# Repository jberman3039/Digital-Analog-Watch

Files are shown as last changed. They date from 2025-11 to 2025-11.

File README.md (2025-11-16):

# Digital-Analog-Watch
The "Digital Analog Watch" is an ATTiny85-based project that displays hours and minutes using and outer and inner rings of LEDs respectively. The project includes a custom drivers to set and get the time for an D3231 RTC via I2C communication and update the LEDs on the PCB with 74HC595 shift registers. To initially set the time on the RTC, uncomment "#define SET_TIME" in main.c and set the values for HOUR, MINUTE, and SECOND. After initially flashing and running the code, this line must be recommented out and the code reflashed. The RTC will continue to keep accurate time as long as VBAT is connected to a power source such as a CR2032 coin cell battery. To flash the code to the ATTiny85, navigate to the src folder and run the command "make flash". This project was inspired by https://github.com/brunob45/watch/tree/master.

# PCB
The PCB was designed in KiCad 9.0.
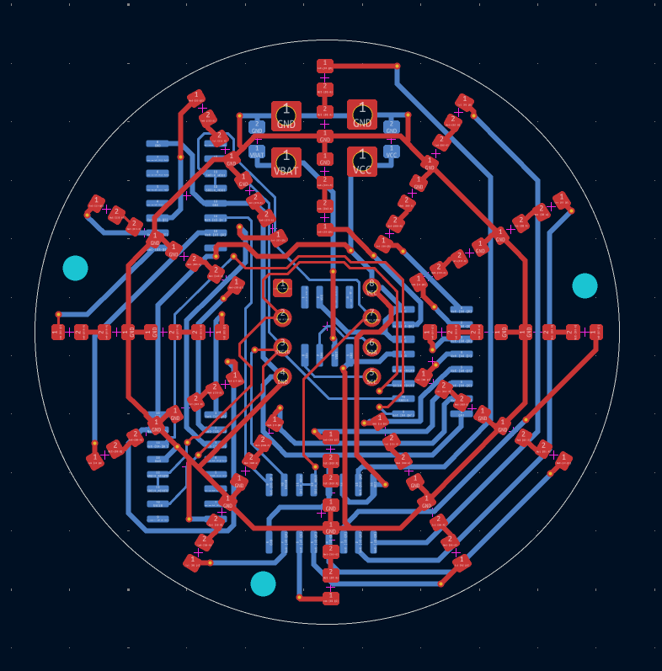
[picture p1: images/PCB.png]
PCB Design

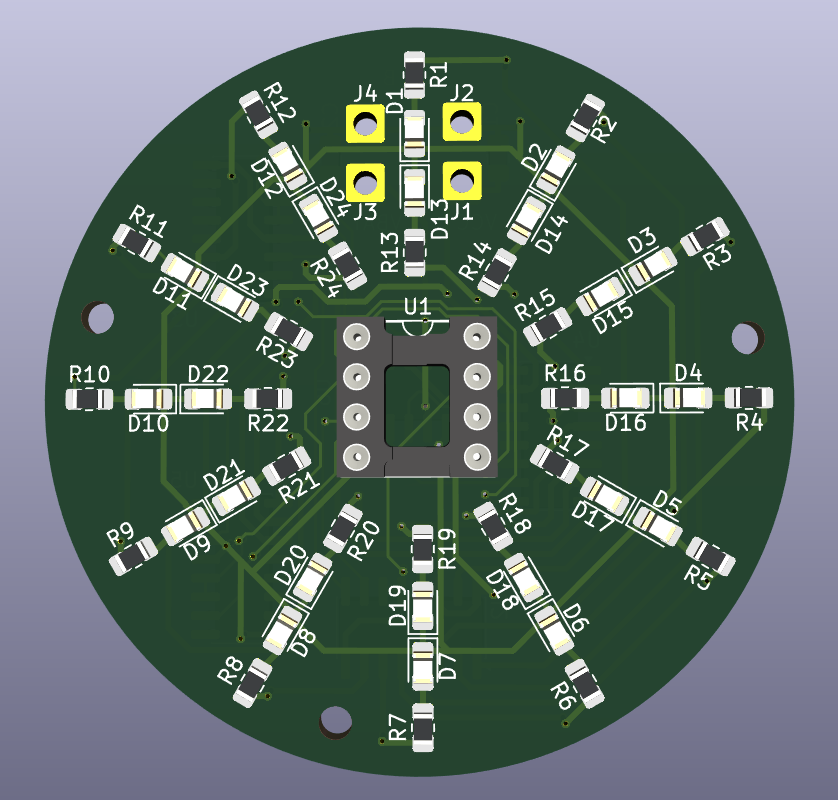
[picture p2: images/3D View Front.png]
PCB Front

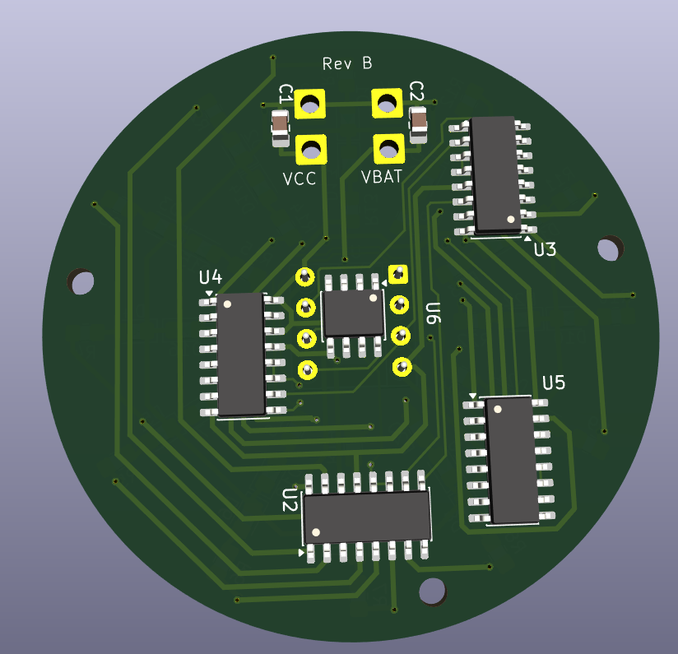
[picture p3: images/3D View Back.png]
PCB Back


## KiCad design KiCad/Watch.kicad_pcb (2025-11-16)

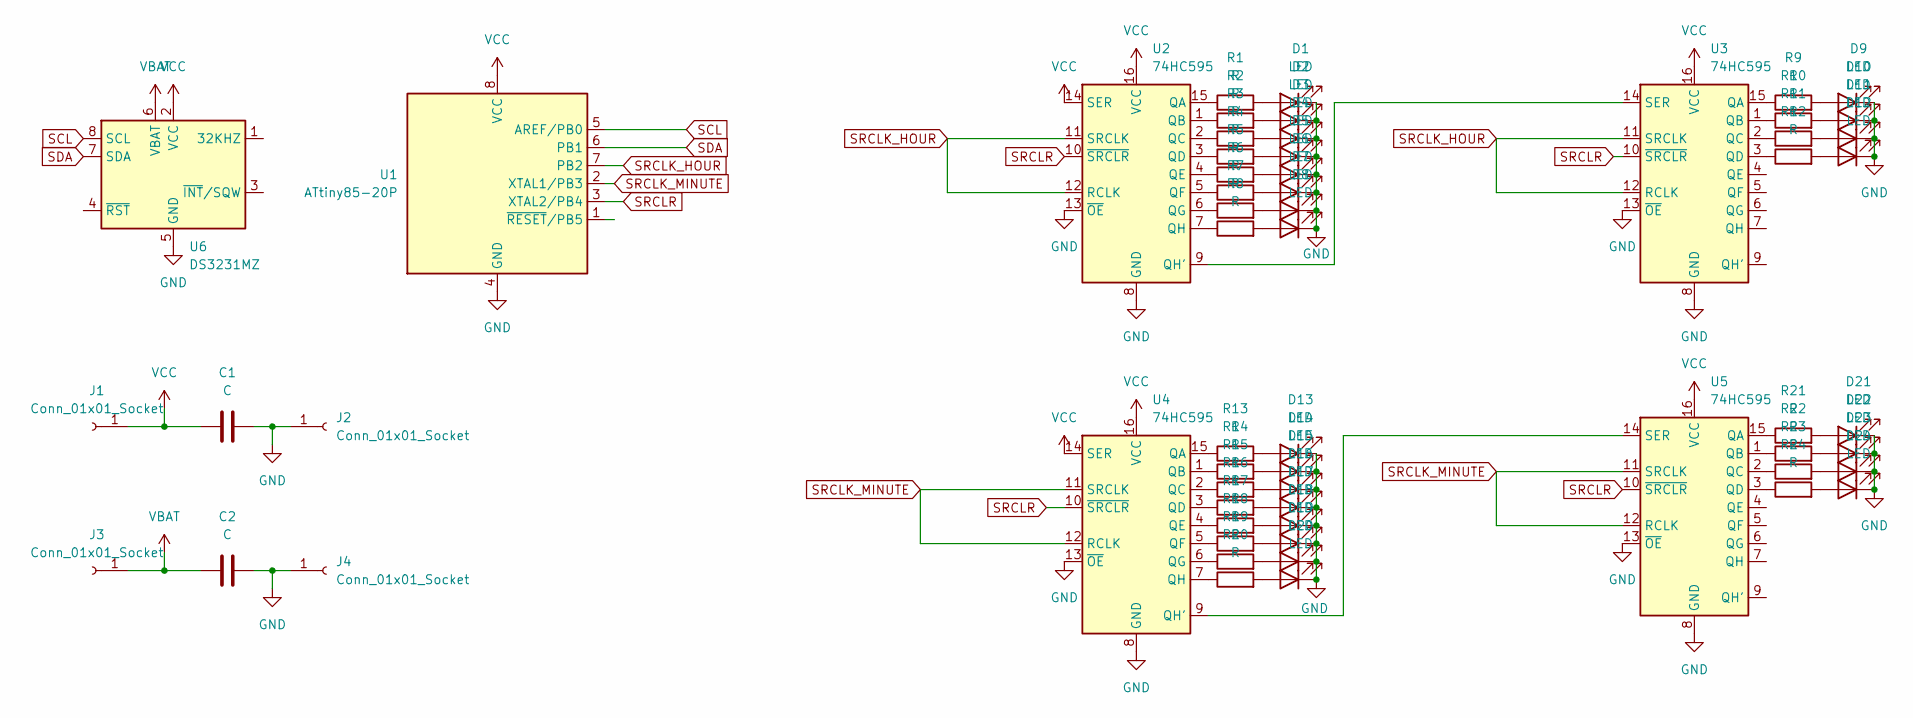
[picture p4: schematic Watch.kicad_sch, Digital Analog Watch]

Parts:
C1, C2: C; C_0805_2012Metric_Pad1.18x1.45mm_HandSolder
D1, D2, D3, D4, D5, D6, D7, D8, D9, D10, D11, D12, D13, D14, D15, D16, D17, D18, D19, D20, D21, D22, D23, D24: LED; LED_0805_2012Metric_Pad1.15x1.40mm_HandSolder
J1, J2, J3, J4: Conn_01x01_Socket; SolderWire-0.75sqmm_1x01_D1.25mm_OD2.3mm
R1, R2, R3, R4, R5, R6, R7, R8, R9, R10, R11, R12, R13, R14, R15, R16, R17, R18, R19, R20, R21, R22, R23, R24: R; R_0805_2012Metric_Pad1.20x1.40mm_HandSolder
U1: ATtiny85-20P; DIP-8_W7.62mm_Socket
U2, U3, U4, U5: 74HC595; SOIC-16_3.9x9.9mm_P1.27mm
U6: DS3231MZ; SOIC-8_3.9x4.9mm_P1.27mm

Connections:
GND: C1.2, C2.2, D1.1 (K), D2.1 (K), D3.1 (K), D4.1 (K), D5.1 (K), D6.1 (K), D7.1 (K), D8.1 (K), D9.1 (K), D10.1 (K), D11.1 (K), D12.1 (K), D13.1 (K), D14.1 (K), D15.1 (K), D16.1 (K), D17.1 (K), D18.1 (K), D19.1 (K), D20.1 (K), D21.1 (K), D22.1 (K), D23.1 (K), D24.1 (K), J2.1, J4.1, U1.4 (GND), U2.8 (GND), U2.13 (~OE), U3.8 (GND), U3.13 (~OE), U4.8 (GND), U4.13 (~OE), U5.8 (GND), U5.13 (~OE), U6.5 (GND)
unnamed: D1.2 (A), R1.2
unnamed: D2.2 (A), R2.2
unnamed: D3.2 (A), R3.2
unnamed: D4.2 (A), R4.2
unnamed: D5.2 (A), R5.2
unnamed: D6.2 (A), R6.2
unnamed: D7.2 (A), R7.2
unnamed: D8.2 (A), R8.2
unnamed: D9.2 (A), R9.2
unnamed: D10.2 (A), R10.2
unnamed: D11.2 (A), R11.2
unnamed: D12.2 (A), R12.2
unnamed: D13.2 (A), R13.2
unnamed: D14.2 (A), R14.2
unnamed: D15.2 (A), R15.2
unnamed: D16.2 (A), R16.2
unnamed: D17.2 (A), R17.2
unnamed: D18.2 (A), R18.2
unnamed: D19.2 (A), R19.2
unnamed: D20.2 (A), R20.2
unnamed: D21.2 (A), R21.2
unnamed: D22.2 (A), R22.2
unnamed: D23.2 (A), R23.2
unnamed: D24.2 (A), R24.2
unnamed: R1.1, U2.15 (QA)
unnamed: R2.1, U2.1 (QB)
unnamed: R3.1, U2.2 (QC)
unnamed: R4.1, U2.3 (QD)
unnamed: R5.1, U2.4 (QE)
unnamed: R6.1, U2.5 (QF)
unnamed: R7.1, U2.6 (QG)
unnamed: U2.9 (QH'), U3.14 (SER)
unnamed: R8.1, U2.7 (QH)
unnamed: R9.1, U3.15 (QA)
unnamed: R10.1, U3.1 (QB)
unnamed: R11.1, U3.2 (QC)
unnamed: R12.1, U3.3 (QD)
unnamed: R13.1, U4.15 (QA)
unnamed: R14.1, U4.1 (QB)
unnamed: R15.1, U4.2 (QC)
unnamed: R16.1, U4.3 (QD)
unnamed: R17.1, U4.4 (QE)
unnamed: R18.1, U4.5 (QF)
unnamed: R19.1, U4.6 (QG)
unnamed: U4.9 (QH'), U5.14 (SER)
unnamed: R20.1, U4.7 (QH)
unnamed: R21.1, U5.15 (QA)
unnamed: R22.1, U5.1 (QB)
unnamed: R23.1, U5.2 (QC)
unnamed: R24.1, U5.3 (QD)
SCL: U1.5 (AREF/PB0), U6.8 (SCL)
SDA: U1.6 (PB1), U6.7 (SDA)
SRCLK_HOUR: U1.7 (PB2), U2.11 (SRCLK), U2.12 (RCLK), U3.11 (SRCLK), U3.12 (RCLK)
SRCLK_MINUTE: U1.2 (XTAL1/PB3), U4.11 (SRCLK), U4.12 (RCLK), U5.11 (SRCLK), U5.12 (RCLK)
SRCLR: U1.3 (XTAL2/PB4), U2.10 (~SRCLR), U3.10 (~SRCLR), U4.10 (~SRCLR), U5.10 (~SRCLR)
VBAT: C2.1, J3.1, U6.6 (VBAT)
VCC: C1.1, J1.1, U1.8 (VCC), U2.14 (SER), U2.16 (VCC), U3.16 (VCC), U4.14 (SER), U4.16 (VCC), U5.16 (VCC), U6.2 (VCC)

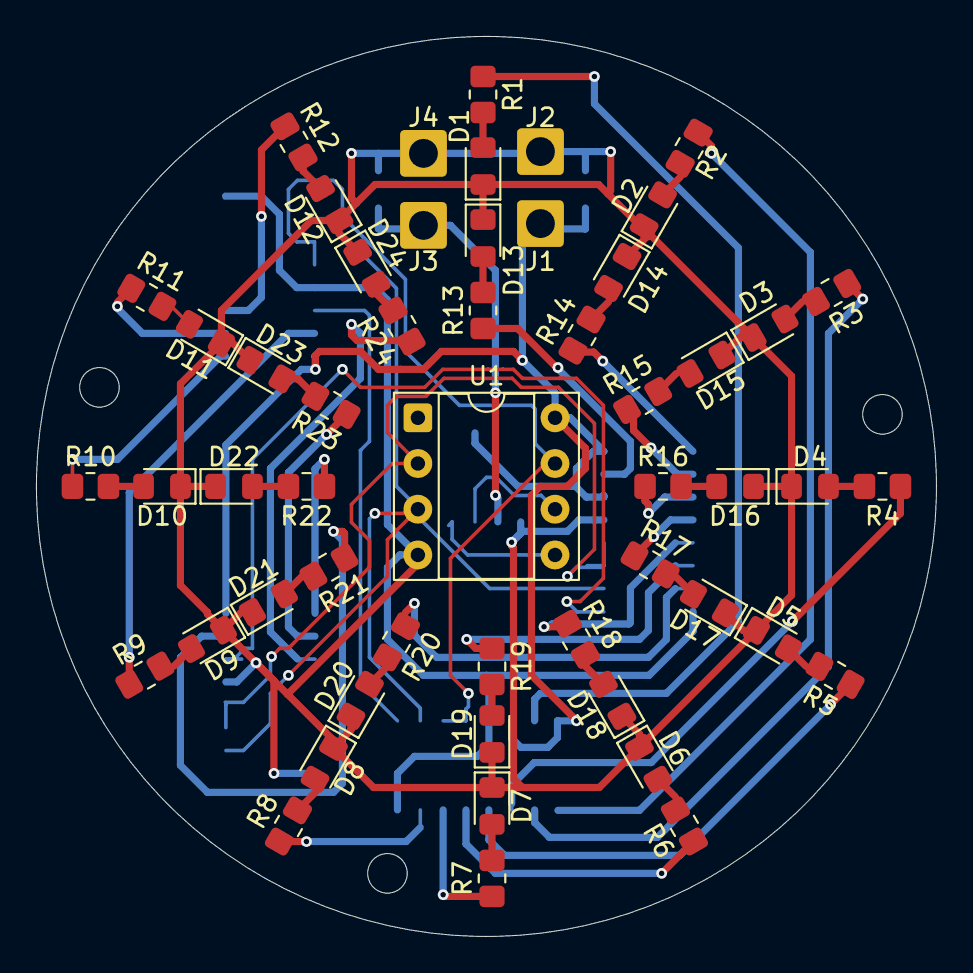
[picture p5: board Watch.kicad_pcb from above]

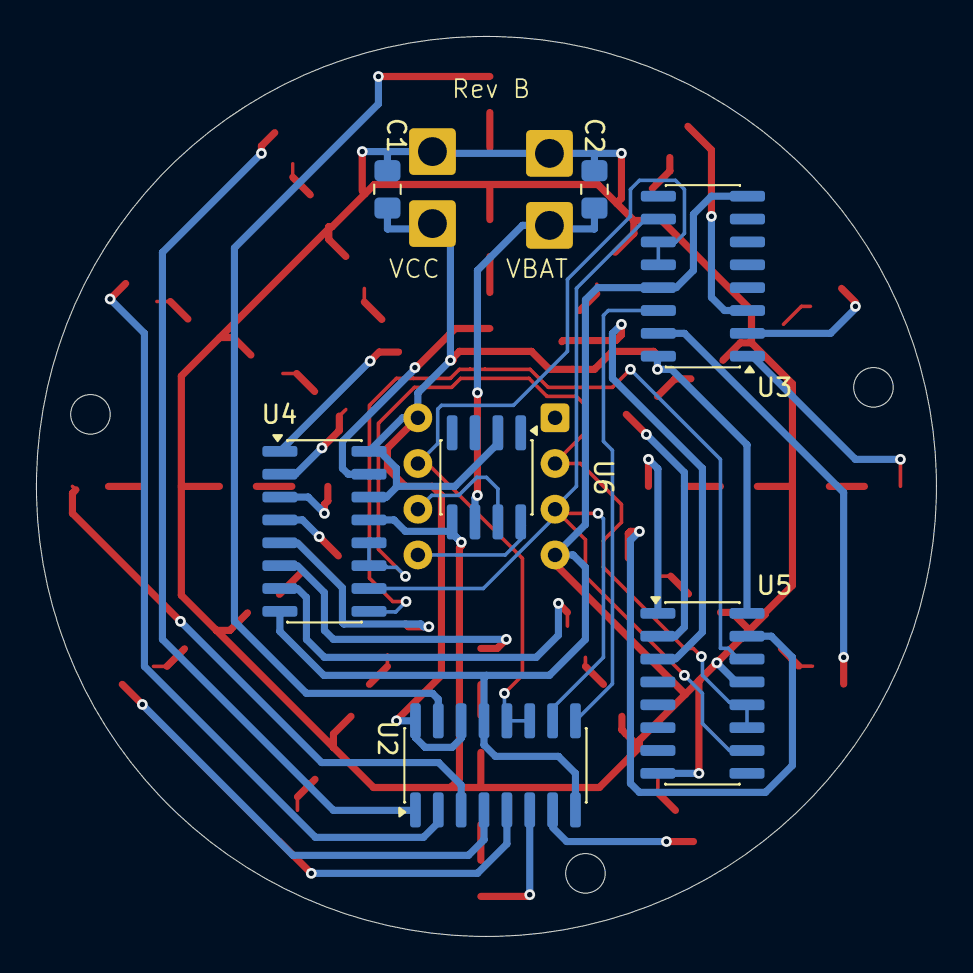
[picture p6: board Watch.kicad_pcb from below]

Board: 2 copper layers, 50.0 x 50.0 mm, 63 parts (7 on the bottom side), 58 nets.

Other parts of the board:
 : MountingHole_2.2mm_M2
 #2,  #3: MountingHole_2.2mm_M2

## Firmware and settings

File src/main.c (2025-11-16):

#include "attiny85.h"
#include "i2c.h"
#include "ds3231.h"
#include "74hc595.h"

//#define SET_TIME // Uncomment to set the current time with the values below on startup
#define HOUR 3
#define MINUTE 34
#define SECOND 50 

volatile char update_counter = 0; // Counter updated by timer0 to control LED update frequency
const char update_period = 5; // Period to update the time at

// Timer/Counter0 Overflow interrupt (interupt vector #5)
void __vector_5(void) __attribute__((signal));
void __vector_5(void)
{
	update_counter++;
}

int main()
{
	// Variables to store the time data from the RTC
	unsigned char rtc_hour;
	unsigned char rtc_minute;

	// Init functions
	init_i2c();
	init_74hc595();

	// Start timer at 1/1024 system clock rate
	TCCR0B |= (1 << 2) | (1 << 0);

	// Enable Time/Counter0 Overflow Interrupt
	TIMSK |= (1 << 1);

	// Enable Global Interrupts
	SREG |= (1 << 7);


	// Set time on the DS3231
	#ifdef SET_TIME
		set_hours(HOUR);
		set_minutes(MINUTE);
		set_seconds(SECOND);
	#endif
		
	// Set inital time on the watch
	get_hours(&rtc_hour);
	get_minutes(&rtc_minute);
	update_time(&rtc_hour, &rtc_minute);


	while (1)
	{
		if (update_counter > update_period)
		{
			// Reset counter
			update_counter = 0;

			// Update time on watch
			get_hours(&rtc_hour);
			get_minutes(&rtc_minute);
			update_time(&rtc_hour, &rtc_minute);
		}
	}
}

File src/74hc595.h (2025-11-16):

#define SRCLK_HOUR_PIN 2 // PB2
#define SRCLK_MINUTE_PIN 3 // PB3
#define SRCLR_PIN 4 // PB4

void init_74hc595();
void clear_sr();
void update_hour(unsigned char* rtc_hour);
void update_minute(unsigned char* rtc_minute);
void update_time(unsigned char* rtc_hour, unsigned char* rtc_minute);
